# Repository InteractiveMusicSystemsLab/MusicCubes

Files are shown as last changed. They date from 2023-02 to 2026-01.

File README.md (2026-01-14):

# Music Cubes

**The software for the cube from D23 is in the D23/blemidi Arduino project.**

The work from C23 team is contained in the C23 folder, and 
the other work from D23 team is contained in the D23 folder.

### Required Arduino libraries

#### Board support:
- Add `https://files.seeedstudio.com/arduino/package_seeeduino_boards_index.json` to Arduino/preferences/Additional Boards Manager URLs
- Then add Seeed XIAO nRF52840
#### Libraries
-  **Seeed Arduino LSM6DS3**
-  **MIDI Library** by Francois Best, lathoub
-  **base64** by Densaugeo
-  **Madgwick** by Arduino
-  **ArduinoBLE** by Arduino

## Contributing

Navigate to the [CONTRIBUTING.md](./CONTRIBUTING.md) file for guidelines on how to contribute to the project.

Music, audio, and other creative works produced using Music Cubes are not considered Contributions and remain the sole property of their creators.

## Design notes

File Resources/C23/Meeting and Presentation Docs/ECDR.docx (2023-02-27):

Abstract:

This project creates a cube or dice that when rolled tells a computer which side it has rolled onto via low-energy Bluetooth to command a musical response through MIDI. The microcontroller used was the Seeed Studio XIAO nRF52840 which has BLE, an accelerometer, a battery controller, and many other sensors that could be useful to future students. This microcontroller is only 20mm by 20mm, allowing the cube to be only one inch. The microcontroller senses which side it is turned onto with the accelerometer and communicates that to the computer where a python script turns that data into MIDI output.

Transcript Title:

Music Randomization Dice Project

Transcript Abstract:

This project creates a cube or dice that when rolled tells a computer which side it has rolled onto via low-energy Bluetooth to command a musical response through MIDI. The microcontroller used was the Seeed Studio XIAO nRF52840 which has BLE, an accelerometer, a battery controller, and many other sensors that could be useful to future students. This microcontroller is only 20mm by 20mm, allowing the cube to be only one inch. The microcontroller senses which side it is turned onto with the accelerometer and communicates that to the computer where a python script turns that data into MIDI output

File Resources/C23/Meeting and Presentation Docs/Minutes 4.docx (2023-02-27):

Minutes 4

- Cube BLE is extremely troublesome
- Found a multitude of videos on how to set up a cube as a midi device. Proving to be pretty difficult with BLE, possibly impossible with our abilities.
- We thought up a new idea for handling the communication and advertising data. Could use python scripts to handle the received data from the cube, while the cube simply just sends sensor values over BLE.
- Look into how to just simply send values over BLE

Matt - Make code for the cube to simply send the X, Y, and Z acceleration data gathered from the IMU

Owen - Work on updating the python code that he has from a previous class

Eli - Re-solder the cube, wires are falling apart a bit

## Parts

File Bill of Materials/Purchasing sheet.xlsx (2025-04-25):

Item | Quantity | Link | Price | Need
TOTAL | 8 |  | 92$ | These components are required to construct 4 musical cubes that can control different aspects of the music at once
nRF52840 | 4 | https://www.digikey.com/en/products/detail/seeed-technology-co.,-ltd/102010469/16652896 | 16$ | This is a combination microcontroller, accelerometer, gyroscope, Bluetooth, Wi-Fi, and microphone that can charge our battery via usb-c. It provides us with tons of options for future work and is tiny.
3.7V 120mAh | 4 | https://www.amazon.com/MSDS-Verified-Part-Number-Rechargeable/dp/B097BLGYPF?s=electronics | 7$ | This is a small battery that can power our micro controller and be charged by it, it fits in about the same footprint as well
Source new battery

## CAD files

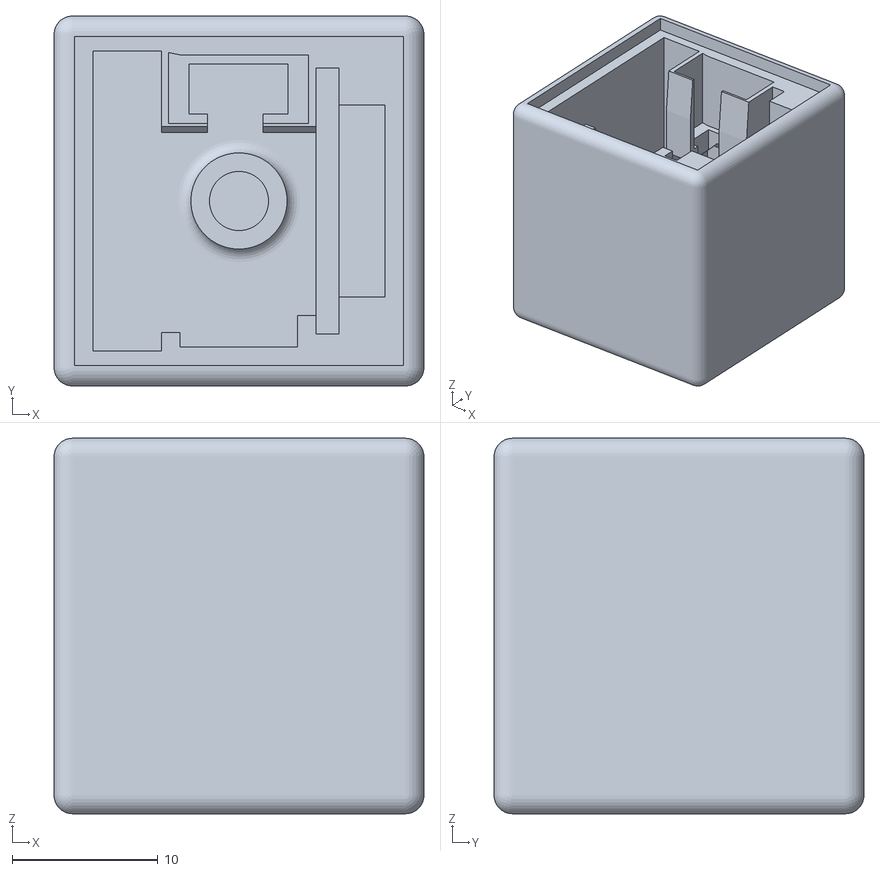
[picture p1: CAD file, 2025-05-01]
Models/SmallCube_MainCase.stl
25.4 x 25.4 x 25.8

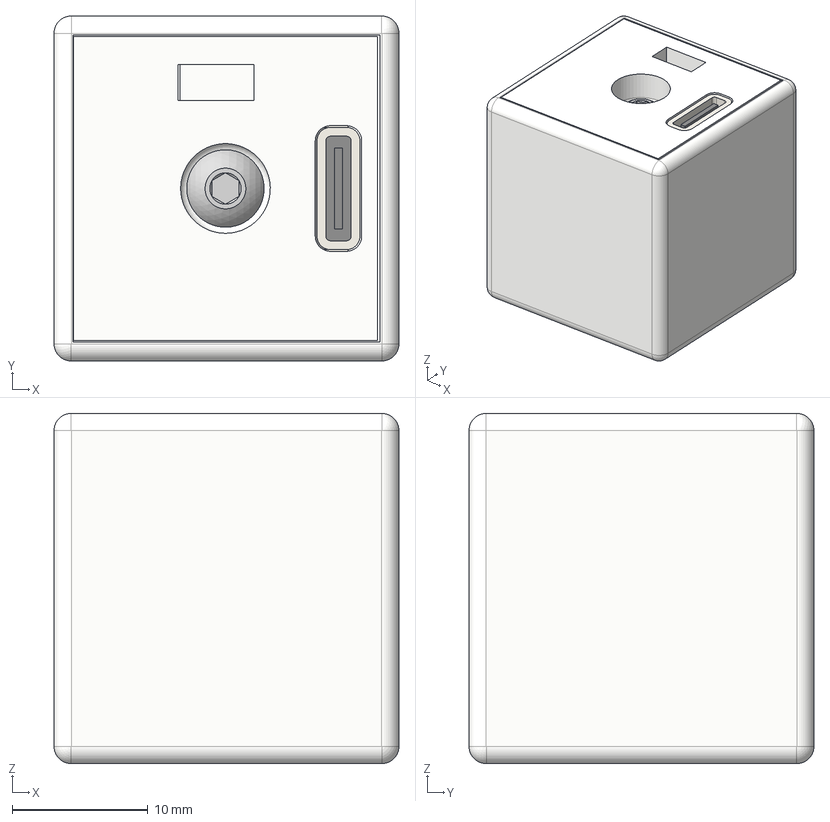
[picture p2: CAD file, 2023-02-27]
Models/C23/musical cube.step
25.4 x 25.4 x 25.8 mm
Seeeduino Xiao
94180A333_Tapered Heat-Set Inserts for Plastic
92095A184_Button Head Hex Drive Screw

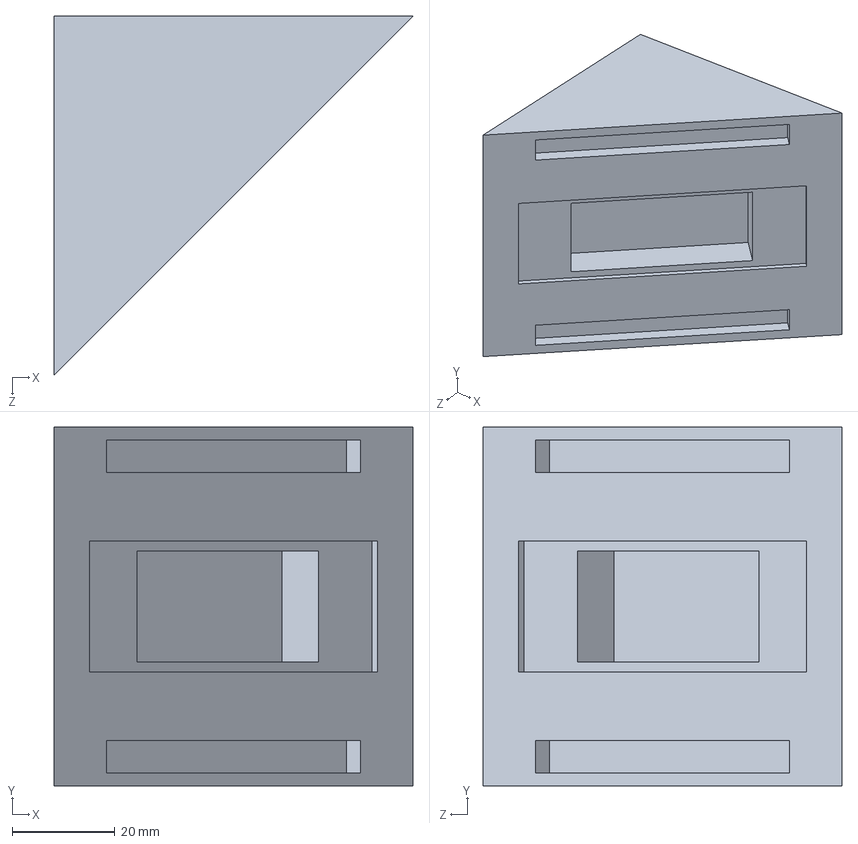
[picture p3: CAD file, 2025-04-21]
Models/C24/Large Dice/Cube Shell - base brickclosure.SLDPRT
69.8 x 69.8 x 69.8 mm

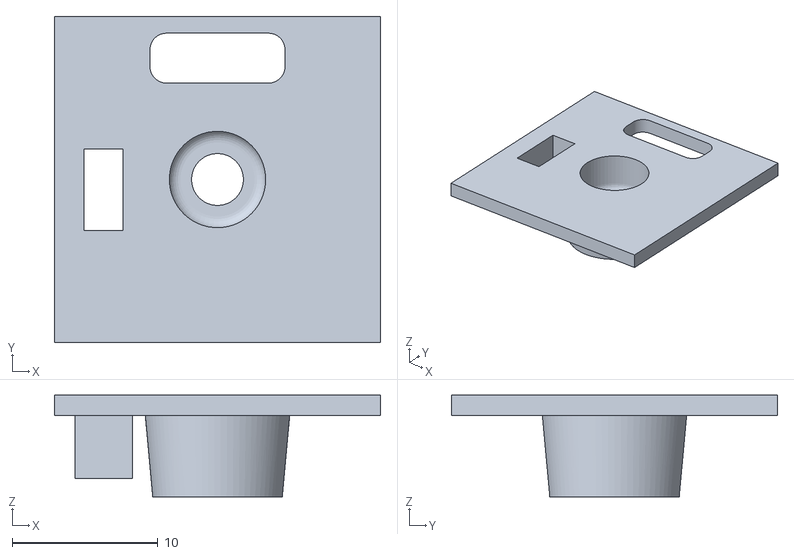
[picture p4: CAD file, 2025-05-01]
Models/SmallCube_Cover.stl
22.4 x 22.4 x 6.98

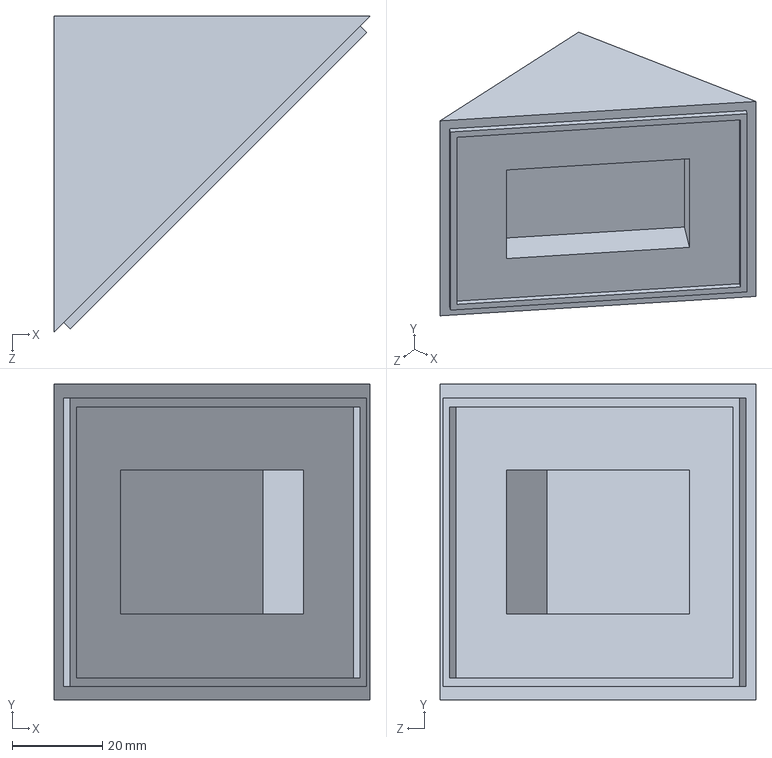
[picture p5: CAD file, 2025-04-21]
Models/C24/Large Dice/Cube Shell - top ring closure.SLDPRT
69.8 x 69.8 x 69.8 mm

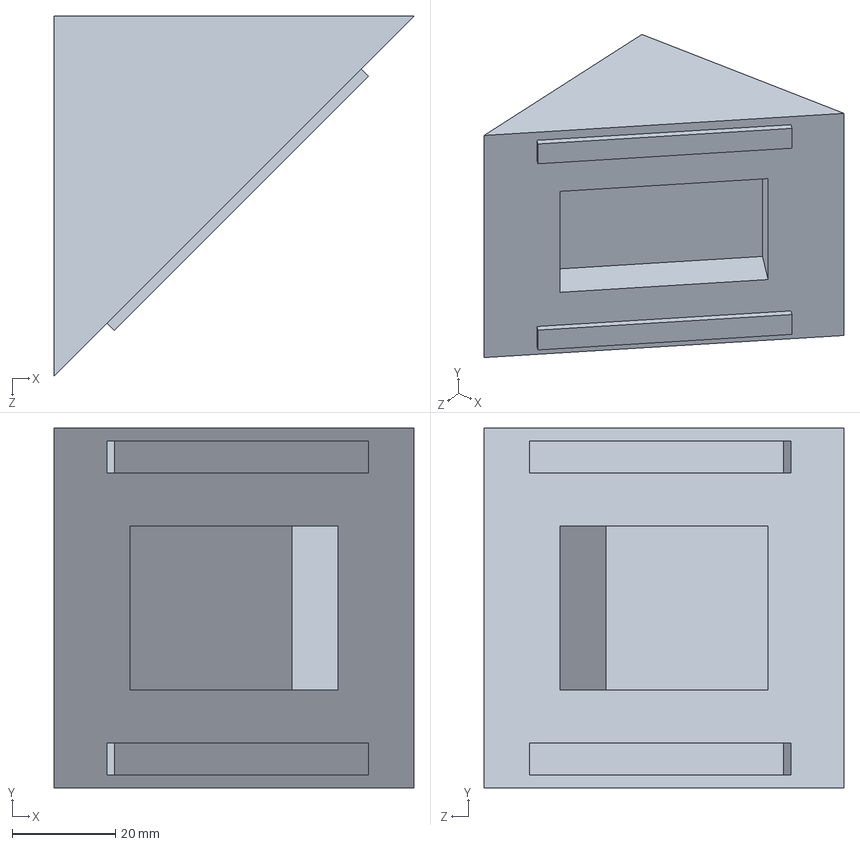
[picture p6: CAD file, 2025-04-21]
Models/C24/Large Dice/Cube Shell - top brick closure.SLDPRT
69.8 x 69.8 x 69.8 mm

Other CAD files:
Models/C24/Large Dice/Cube Shell - base ring closure.SLDPRT
Models/C24/Large Dice/Cube Shell - base brickclosure.STL
Models/C24/Large Dice/Cube Shell - base ring closure.STL
Models/C24/Large Dice/Cube Shell - top brick closure.STL
Models/C24/Large Dice/Cube Shell - top ring closure.STL

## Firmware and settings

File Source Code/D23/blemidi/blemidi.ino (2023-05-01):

/*********************************************************************
 This is an example for our nRF52 based Bluefruit LE modules

 Pick one up today in the adafruit shop!

 Adafruit invests time and resources providing this open source code,
 please support Adafruit and open-source hardware by purchasing
 products from Adafruit!

 MIT license, check LICENSE for more information
 All text above, and the splash screen below must be included in
 any redistribution
*********************************************************************/

/* This example requires following library
 * - https://github.com/FortySevenEffects/arduino_midi_library/ (MIDI Library)
 *
 * For BLE MIDI Setup on PC/mobile checkout our learn guide
 * - https://learn.adafruit.com/wireless-untztrument-using-ble-midi/ble-midi-setup
 */

#include <Arduino.h>
#include <bluefruit.h>
#include <MIDI.h>
#include <LSM6DS3.h>
#include <MadgwickAHRS.h>
#include <base64.hpp>

#define CC_YAW 0
#define CC_PITCH 1
#define CC_ROLL 2
#define CC_CHANGE_CHANNEL 55
#define MIDI_DICE 59
#define SYSEX_BUFFER_SIZE 1024

BLEDis bledis;
BLEMidi blemidi;
LSM6DS3 imu(I2C_MODE, 0x6A);
BLEUart bleuart;
// initialize a Madgwick filter:
Madgwick filter;
// sensor's sample rate is fixed at:
const int sensorRate = 104;
const float gyroThresh = 0.15;
const float accelThresh = 0.013;
const int initialDetectTime = 1000; // time to allow CC signals from other cubes to prevent interference.
int channel = 2;  // this can change if interference detected
unsigned long microsPerReading, microsPrevious;

// Create a new instance of the Arduino MIDI Library,
// and attach BluefruitLE MIDI as the transport.
MIDI_CREATE_BLE_INSTANCE(blemidi);

void setup() {
  Serial.begin(115200);

  unsigned long start_time = millis();
  while (!Serial && (millis() - start_time < 1000)) {
    delay(10);
  }

  // Generate a unique Base64-encoded string based on device's UID
  uint8_t uid[16];
  memcpy(uid, (const void *)NRF_FICR->DEVICEADDR, sizeof(uid));
  unsigned char unique_string[11];
  encode_base64(uid, sizeof(uid), unique_string);
  unique_string[9] = '\0';
  unique_string[10] = '\0';
  // Print the unique string
  Serial.println((char *)unique_string);

  Serial.println("Adafruit Bluefruit52 MIDI over Bluetooth LE Example");

  // Config the peripheral connection with maximum bandwidth
  // more SRAM required by SoftDevice
  // Note: All config***() function must be called before begin()
  Bluefruit.configPrphBandwidth(BANDWIDTH_MAX);

  Bluefruit.begin();
  Bluefruit.setTxPower(4);  // Check bluefruit.h for supported values

  // Setup the on board blue LED to be enabled on CONNECT
  Bluefruit.autoConnLed(true);

  // Configure and Start Device Information Service
  bledis.setManufacturer("Adafruit Industries");
  bledis.setModel("Bluefruit Feather52");
  bledis.begin();

  // Initialize MIDI, and listen to all MIDI channels
  // This will also call blemidi service's begin()
  MIDI.begin(MIDI_CHANNEL_OMNI);

  // Attach the handleNoteOn function to the MIDI Library. It will
  // be called whenever the Bluefruit receives MIDI Note On messages.
  MIDI.setHandleNoteOn(handleNoteOn);

  // Do the same for MIDI Note Off messages.
  MIDI.setHandleNoteOff(handleNoteOff);

  // MIDI.setHandleControlChange(handleControlChange);


  // Set up and start advertising
  startAdv((char *)unique_string);

  // Start MIDI read loop
  Scheduler.startLoop(midiRead);

  imu.settings.gyroEnabled = 1;              // Can be 0 or 1
  imu.settings.gyroRange = 2000;             // Max deg/s.  Can be: 125, 245, 500, 1000, 2000
  imu.settings.gyroSampleRate = sensorRate;  // Hz.  Can be: 13, 26, 52, 104, 208, 416, 833, 1666
  imu.settings.gyroBandWidth = 200;          // Hz.  Can be: 50, 100, 200, 400;
  // imu.settings.gyroFifoEnabled = 1;  //Set to include gyro in FIFO
  // imu.settings.gyroFifoDecimation = 1;  //set 1 for on /1

  imu.settings.accelEnabled = 1;
  imu.settings.accelRange = 2;                // Max G force readable.  Can be: 2, 4, 8, 16
  imu.settings.accelSampleRate = sensorRate;  // Hz.  Can be: 13, 26, 52, 104, 208, 416, 833, 1666, 3332, 6664, 13330
  imu.settings.accelBandWidth = 200;          // Hz.  Can be: 50, 100, 200, 400;
  // imu.settings.accelFifoEnabled = 1;  //Set to include accelerometer in the FIFO
  // imu.settings.accelFifoDecimation = 1;  //set 1 for on /1
  imu.settings.tempEnabled = 1;

  imu.begin();

  filter.begin(sensorRate);

  // initialize variables to pace updates to correct rate
  microsPerReading = 1000000 / sensorRate;
  microsPrevious = micros();
}

void startAdv(char *unique_string) {

  char name[30];
  strcpy(name, "Cube ");
  strcat(name, unique_string);

  Bluefruit.setName(name);
  // Set General Discoverable Mode flag
  Bluefruit.Advertising.addFlags(BLE_GAP_ADV_FLAGS_LE_ONLY_GENERAL_DISC_MODE);

  // Advertise TX Power
  Bluefruit.Advertising.addTxPower();

  // Advertise BLE MIDI Service
  Bluefruit.Advertising.addService(blemidi);

  // Secondary Scan Response packet (optional)
  // Since there is no room for 'Name' in Advertising packet
  Bluefruit.ScanResponse.addName();

  /* Start Advertising
	 * - Enable auto advertising if disconnected
	 * - Interval:  fast mode = 20 ms, slow mode = 152.5 ms
	 * - Timeout for fast mode is 30 seconds
	 * - Start(timeout) with timeout = 0 will advertise forever (until connected)
	 *
	 * For recommended advertising interval
	 * https://developer.apple.com/library/content/qa/qa1931/_index.html
	 */
  Bluefruit.Advertising.restartOnDisconnect(true);
  Bluefruit.Advertising.setInterval(32, 244);  // in unit of 0.625 ms
  Bluefruit.Advertising.setFastTimeout(30);    // number of seconds in fast mode
  Bluefruit.Advertising.start(0);              // 0 = Don't stop advertising after n seconds
}

void handleNoteOn(byte channel, byte pitch, byte velocity) {
  // Log when a note is pressed.
  // Serial.printf("Note on: channel = %d, pitch = %d, velocity - %d", channel, pitch, velocity);
  // Serial.println();
}

void handleNoteOff(byte channel, byte pitch, byte velocity) {
  // Log when a note is released.
  // Serial.printf("Note off: channel = %d, pitch = %d, velocity - %d", channel, pitch, velocity);
  // Serial.println();
}

void handleControlChange(byte ccChannel, byte control, byte value) {
  Serial.printf("cc: channel = %d, pitch = %d, velocity - %d", ccChannel, control, value);
  Serial.println();
  if (control == CC_CHANGE_CHANNEL) {
    channel = ccChannel;
  }
}

// Set up filter coefficients (adjust as needed)
float alpha = 1;
float dt = 0.005;

float heading = 0;
float pitch = 0;
float roll = 0;

int prevOutputH, prevOutputP, prevOutputR;
int outputH = 64;
int outputP = 64;
int outputR = 64;

// Variables to store the previous readings.
float prev_ax = 0, prev_ay = 0, prev_az = 0;
float prev_gx = 0, prev_gy = 0, prev_gz = 0;

int stillCounter = 0;
int movingCounter = 0;
bool isMoving;
int lastDice = 0;
bool sendingMidi = false;
uint32_t lastNotConnectedTime = 0;
void loop() {
  // Don't continue if we aren't connected.
  if (!Bluefruit.connected()) {
    lastNotConnectedTime = millis();
    return;
  }

  // Don't continue if the connected device isn't ready to receive messages.
  if (!blemidi.notifyEnabled()) {
    return;
  }
  unsigned long microsNow;

  float ax, ay, az;  // Acceleration readings
  float gx, gy, gz;  // Gyroscope readings

  // check if it's time to read data and update the filter
  microsNow = micros();
  if (!sendingMidi && millis() - lastNotConnectedTime > initialDetectTime) {
    sendingMidi = true;
    Serial.println("NOW SENDING MIDI");
  }

  // check if the IMU is ready to read:
  if (microsNow - microsPrevious >= microsPerReading) {
    // read accelerometer & gyrometer:
    ax = imu.readFloatAccelX();
    ay = imu.readFloatAccelY();
    az = imu.readFloatAccelZ();
    gx = imu.readFloatGyroX();
    gy = imu.readFloatGyroY();
    gz = imu.readFloatGyroZ();

    // update the filter, which computes orientation:
    filter.updateIMU(gx, gy, gz, ax, ay, az);

    // print the heading, pitch and roll
    roll = filter.getRoll();
    pitch = filter.getPitch();
    heading = filter.getYaw();

    // increment previous time, so we keep proper pace
    microsPrevious = microsPrevious + microsPerReading;

    // Calculate the change in acceleration and angular velocity.
    float delta_ax = absolute_difference(ax, prev_ax);
    float delta_ay = absolute_difference(ay, prev_ay);
    float delta_az = absolute_difference(az, prev_az);
    float delta_gx = absolute_difference(gx, prev_gx);
    float delta_gy = absolute_difference(gy, prev_gy);
    float delta_gz = absolute_difference(gz, prev_gz);

    // Update the previous values.
    prev_ax = ax;
    prev_ay = ay;
    prev_az = az;
    prev_gx = gx;
    prev_gy = gy;
    prev_gz = gz;

    // Calculate the magnitudes of the change in acceleration and angular velocity.
    float delta_accel_magnitude = magnitude(delta_ax, delta_ay, delta_az);
    float delta_gyro_magnitude = magnitude(delta_gx, delta_gy, delta_gz);

    bool nowMoving = false;
    if (delta_accel_magnitude < accelThresh && delta_gyro_magnitude < gyroThresh) {
      nowMoving = false;
    } else {
      nowMoving = true;
    }

    if (nowMoving) {
      stillCounter = 0;
      movingCounter++;
    } else {
      movingCounter = 0;
      stillCounter++;
    }

    if (stillCounter > 10 && isMoving) {
      isMoving = false;
      movingCounter = 0;
      // Serial.println("STILL");
      int pitch = MIDI_DICE + calculateDice(ax, ay, az);
      if (sendingMidi && pitch != lastDice) {
        MIDI.sendNoteOn(pitch, 60, channel);
        lastDice = pitch;
      }
      
    } else if (movingCounter > 10 && !isMoving) {
      isMoving = true;
      stillCounter = 0;
      Serial.println("MOVING");
    }

    outputH = (int)((heading / 180.0 + 1) / 2 * 127);
    outputR = (int)((roll / 180.0 + 1) / 2 * 127);
    outputP = (int)((pitch / 180.0 + 1) / 2 * 127);
    if (isMoving && sendingMidi) {
      if (lastDice != 0) {
        MIDI.sendNoteOff(lastDice, 0, channel);
        lastDice = 0;
      }
      if (outputH != prevOutputH) {
        prevOutputH = outputH;
        MIDI.sendControlChange(CC_YAW, (int)outputH, channel);
      }
      if (outputR != prevOutputR) {
        prevOutputR = outputR;
        MIDI.sendControlChange(CC_ROLL, (int)outputR, channel);
      }
      if (outputP != prevOutputP) {
        prevOutputP = outputP;
        MIDI.sendControlChange(CC_PITCH, (int)outputP, channel);
      }
    }
  }
  // midiRead should be run as often as possible
  midiRead();
}

void midiRead() {
  // Don't continue if we aren't connected.
  if (!Bluefruit.connected()) {
    return;
  }

  // Don't continue if the connected device isn't ready to receive messages.
  if (!blemidi.notifyEnabled()) {
    return;
  }

  // read any new MIDI messages
  MIDI.read();
}

// Function to calculate the absolute difference between two values.
float absolute_difference(float a, float b) {
  return abs(a - b);
}

int calculateDice(float x, float y, float z) {
  const float threshold = 0.8;
  if (x > threshold) {
    return 1;
  } else if (x < -threshold) {
    return 6;
  } else if (y > threshold) {
    return 2;
  } else if (y < -threshold) {
    return 5;
  } else if (z > threshold) {
    return 3;
  } else if (z < -threshold) {
    return 4;
  } else {
    // In case the accelerometer is not in a stable position
    return -1;
  }
}

// Function to calculate the magnitude of a vector.
float magnitude(float x, float y, float z) {
  return sqrt(x * x + y * y + z * z);
}


byte sysexBuffer[SYSEX_BUFFER_SIZE];
uint16_t sysexIndex = 0;
bool sysexActive = false;

// ableton doesn't route SysEx back to other cubes so doesn't work
// void handleSysEx(byte* sysex, uint16_t length, bool complete) {
//   if (complete) {
//     // Add the last chunk of the SysEx message to the buffer
//     memcpy(&sysexBuffer[sysexIndex], sysex, length);
//     sysexIndex += length;
//     sysexActive = false;
//     // Call the function to process the complete SysEx message
//     processSysEx(sysexBuffer, sysexIndex);
//     // Reset the buffer and index for the next message
//     memset(sysexBuffer, 0, SYSEX_BUFFER_SIZE);
//     sysexIndex = 0;
//   } else {
//     // Add the current chunk of the SysEx message to the buffer
//     memcpy(&sysexBuffer[sysexIndex], sysex, length);
//     sysexIndex += length;
//     sysexActive = true;
//   }
// }

// void processSysEx(byte* sysex, unsigned int length) {
//   // Process the complete SysEx message
//   // For example, print the data to the serial monitor
//   Serial.println("SysEx message received:");
//   for (int i = 0; i < length; i++) {
//     Serial.print(sysex[i], HEX);
//     Serial.print(" ");
//   }
//   Serial.println();
// }

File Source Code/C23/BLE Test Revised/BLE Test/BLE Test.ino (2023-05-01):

#include <ArduinoBLE.h>
#include <LSM6DS3.h>
#include <Wire.h>

LSM6DS3 myIMU(I2C_MODE, 0x6A);
BLEService accelService("1101");
BLEFloatCharacteristic accelCharX("0099b53a-b473-11ed-afa1-0242ac120002", BLERead | BLENotify);
BLEFloatCharacteristic accelCharY("0099b8a0-b473-11ed-afa1-0242ac120002", BLERead | BLENotify);
BLEFloatCharacteristic accelCharZ("0099ba12-b473-11ed-afa1-0242ac120002", BLERead | BLENotify);

void setup() {
  // Serial.begin(9600);
  // while (!Serial)
  //   ;

  myIMU.begin();

  // if (myIMU.begin() != 0) {
  //   Serial.println("Device error");
  // } else {
  //   Serial.println("Device OK!");
  // }

  pinMode(LED_BUILTIN, OUTPUT);
  if (!BLE.begin()) {
    // Serial.println("Starting BLE failed!");
    while (1)
      ;
  }

  BLE.setLocalName("AccelerometerData");
  BLE.setAdvertisedService(accelService);
  accelService.addCharacteristic(accelCharX);
  accelService.addCharacteristic(accelCharY);
  accelService.addCharacteristic(accelCharZ);
  BLE.addService(accelService);


  BLE.advertise();
  Serial.println("Bluetooth device active, waiting for connections...");
}

void loop() {
  BLEDevice central = BLE.central();

  if (central) {
    // Serial.print("Connected to central: ");
    // Serial.println(central.address());
    digitalWrite(LED_BUILTIN, HIGH);

    while (central.connected()) {
      float accelx = myIMU.readFloatAccelX();
      float accely = myIMU.readFloatAccelY();
      float accelz = myIMU.readFloatAccelZ();
      //float accelyRaw = map(accely, 0, 1023, 0, 100);
      //float accelzRaw = map(accelz, 0, 1023, 0, 100);

      // Serial.print("Accelx = ");
      // Serial.println(accelx);
      // Serial.print("Accely = ");
      // Serial.println(accely);
      // Serial.print("Accelz = ");
      // Serial.println(accelz);
      accelCharX.writeValue(accelx);
      accelCharY.writeValue(accely);
      accelCharZ.writeValue(accelz);
      delay(200);
    }
  }

  digitalWrite(LED_BUILTIN, LOW);
  // Serial.print("Disconnected from central: ");
  // Serial.println(central.address());
}

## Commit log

2023-05-01 updated files, updated README.md
    [Musical cube components.xlsx, Purchasing sheet.xlsx, musical cube.step]
2025-04-25 Edited Battery item
    Old battery unavailable, source new one.
    [Purchasing sheet.xlsx]
2025-05-01 Mini Cube STL files
    Split mini cube from .step format to two separate stl files for each part of the cube.
    [SmallCube_Cover.stl, SmallCube_MainCase.stl]
